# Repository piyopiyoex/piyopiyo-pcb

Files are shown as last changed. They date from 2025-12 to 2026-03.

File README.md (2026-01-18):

# Piyopiyo PCB

Piyopiyo PCB は、Elixir 入門者コミュニティ
[piyopiyo.ex](https://piyopiyoex.connpass.com/) のためのオリジナル基板です。
ワークショップや自習で扱いやすく、回路やソフトウェアも後から読み解きやすい構成を目指しています。

<p align="center">
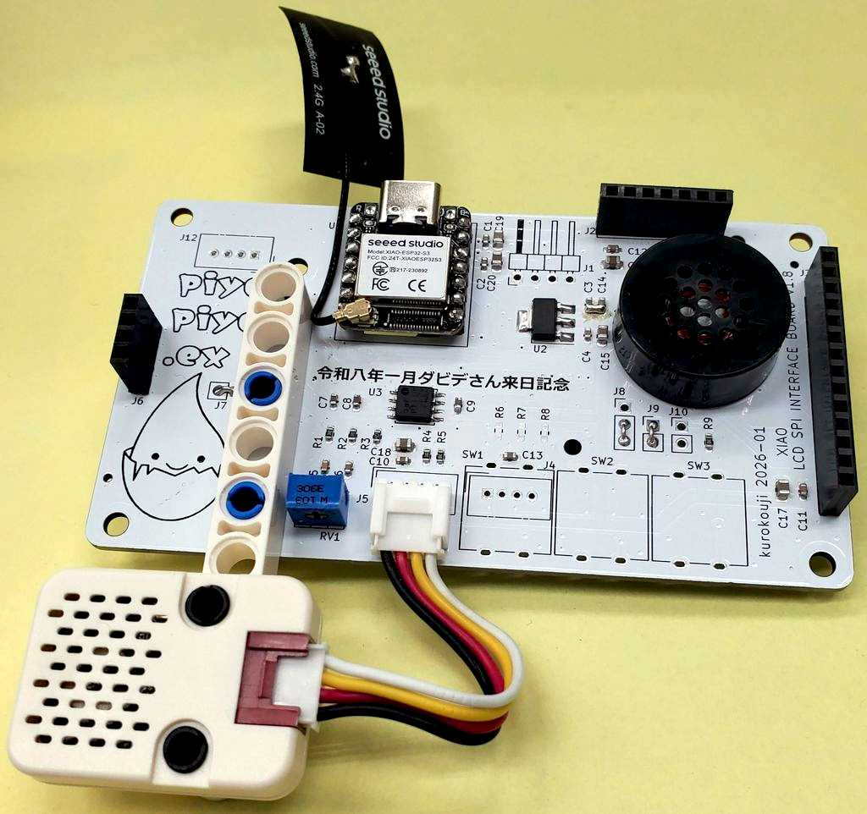
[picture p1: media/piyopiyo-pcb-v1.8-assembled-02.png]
Piyopiyo PCB assembled
  
</p>

## ハードウェア

ハードウェア設計データの概要や各ファイルの用途は、
[`hardware/README.md`](./hardware/) を参照してください。

<p align="center">
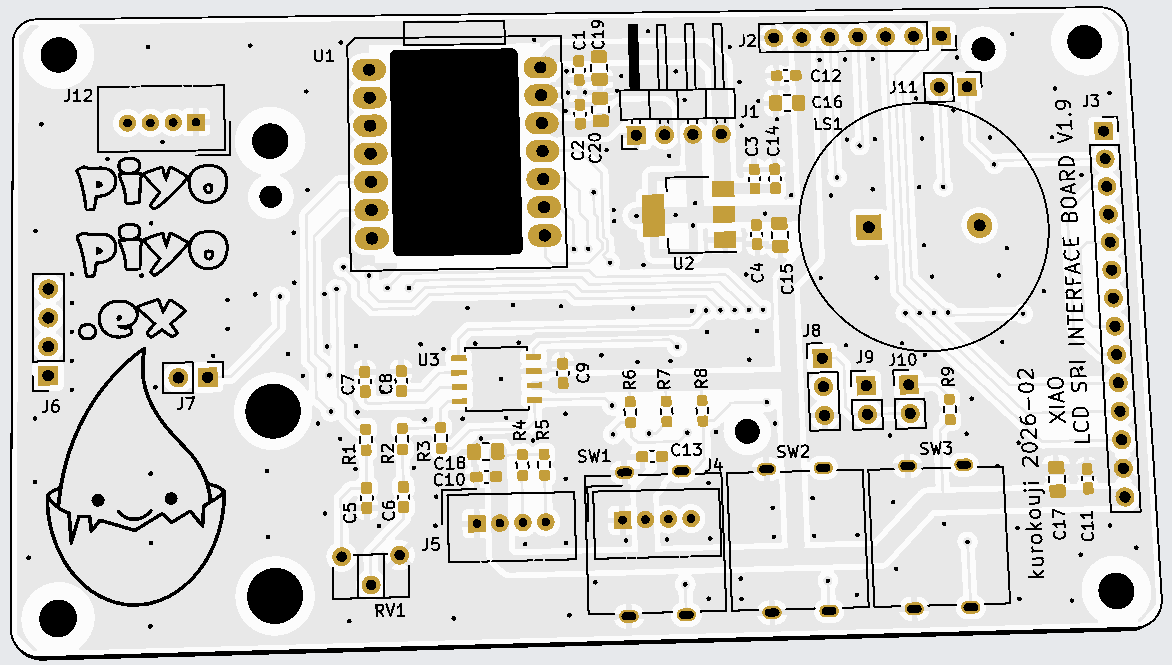
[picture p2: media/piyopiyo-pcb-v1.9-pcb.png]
Piyopiyo PCB bare board
  
</p>

## Attribution & Licensing

- ハードウェア設計（`hardware/`）: [kurokouji](https://github.com/kurokouji)
- `hardware/` は CERN-OHL-P-2.0、`manuals/` / `media/` / `.md` は原則 CC BY 4.0
- ライセンスの詳細: [`LICENSE.md`](./LICENSE.md)

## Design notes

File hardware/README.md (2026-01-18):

# hardware

`hardware/` には、Piyopiyo PCB のハードウェア設計データをまとめています。

主な内容は次のとおりです。

```text
hardware/
├── vX.Y/                         # バージョンごとの設計データ一式
│   ├── kicad/                    # KiCad プロジェクト一式（.kicad_pro/.kicad_sch/.kicad_pcb 等）
│   │   └── piyopiyo-pcb-vX.Y/    # プロジェクトフォルダ（フットプリント/ライブラリ含む）
│   ├── fab/
│   │   └── jlcpcb/               # JLCPCB 向け製造データ
│   │       ├── bom.csv           # 部品表（LCSC Part # を含む）
│   │       ├── cpl.csv           # 部品実装位置（Pick & Place）
│   │       └── gerber.zip        # 基板製造用 Gerber 一式
│   └── docs/
│       └── piyopiyo-pcb.pdf      # 回路図・基板レイアウトの PDF 出力
├── reference/                    # モジュール寸法などの参考資料
└── CHANGELOG.md                  # バージョン間の変更履歴
```

## ライセンスと帰属

このディレクトリのハードウェア設計データは kurokouji により作成されました。

ライセンスの詳細は [`LICENSE.md`](../LICENSE.md) を参照してください。

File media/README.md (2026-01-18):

# media

`media/` には、Piyopiyo PCB に関する画像ファイルをまとめています。

例:

- `piyopiyo-pcb-vX.Y-assembled.png`  
  部品を実装した基板の写真

- `piyopiyo-pcb-vX.Y-pcb.png`  
  裸基板のみの写真

どの版の写真かは、ファイル名の `vX.Y` で判別します。

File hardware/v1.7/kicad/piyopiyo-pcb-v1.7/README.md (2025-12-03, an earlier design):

# KiCad プロジェクト

このディレクトリには、Piyopiyo PCB の KiCad プロジェクトファイルをまとめています。

主なファイル:

- `.kicad_pro` — プロジェクト本体
- `.kicad_sch` — 回路図
- `.kicad_pcb` — 基板レイアウト
- `Library.pretty/` — フットプリントライブラリ
- `fp-lib-table`, `fp-info-cache` など — KiCad が生成する設定・キャッシュ

KiCad でこの版の回路やパターンを編集したい場合は、このディレクトリ内の `.kicad_pro` を開いてください。

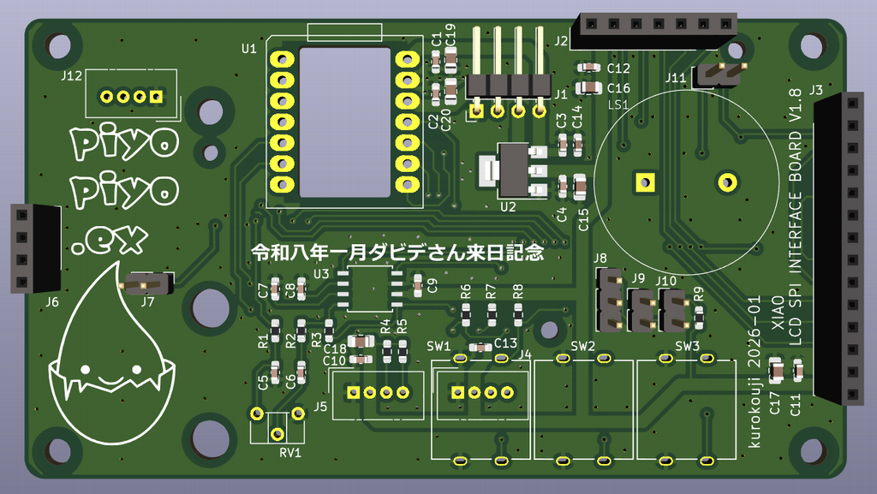
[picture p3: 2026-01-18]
media/piyopiyo-pcb-v1.8-pcb.png

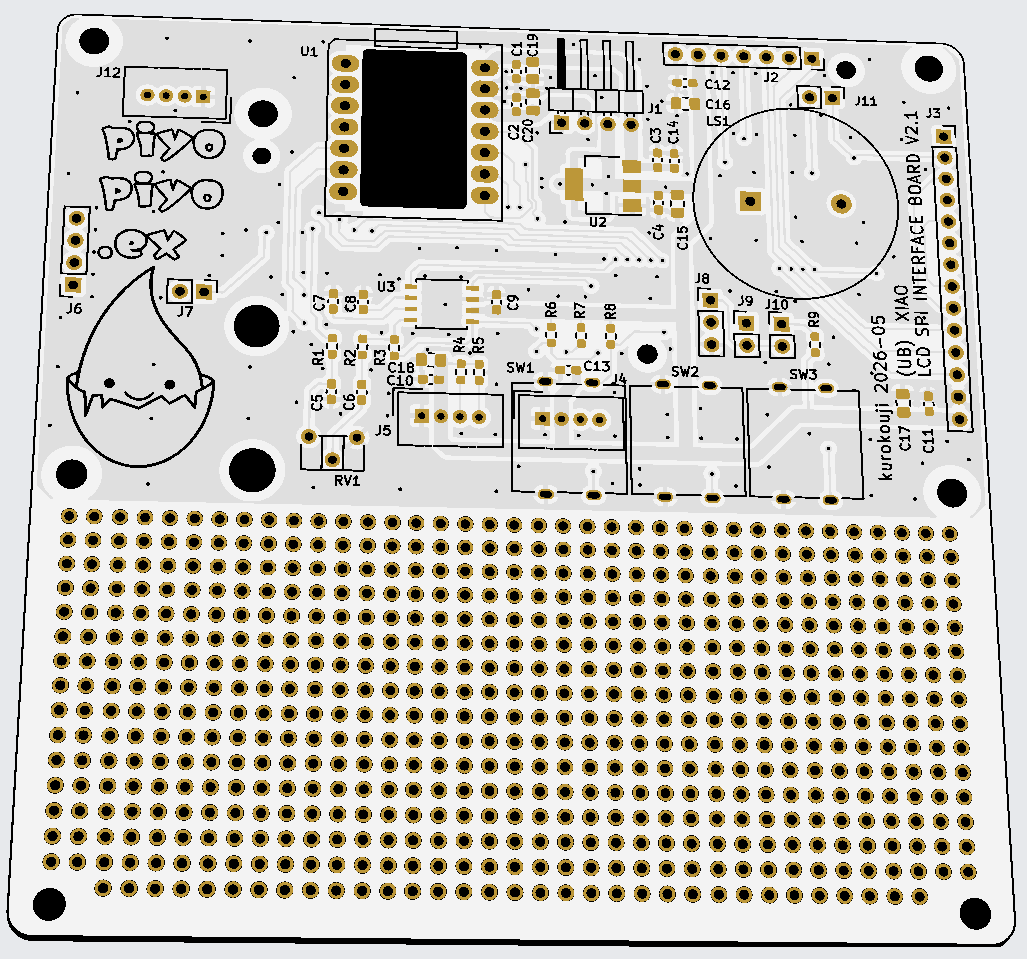
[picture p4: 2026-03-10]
media/piyopiyo-pcb-v2.1-pcb--universal-bottom.png

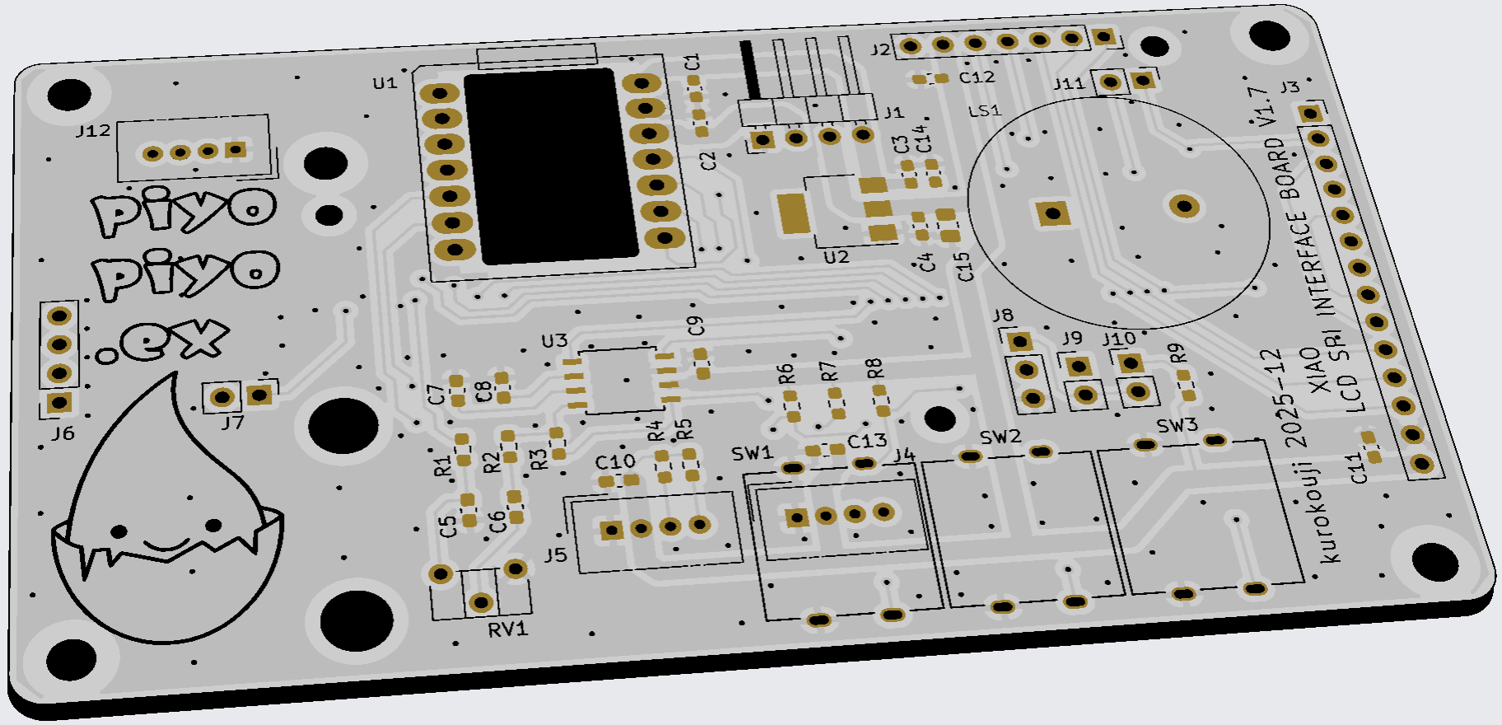
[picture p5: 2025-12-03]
media/piyopiyo-pcb-v1.7-pcb.png

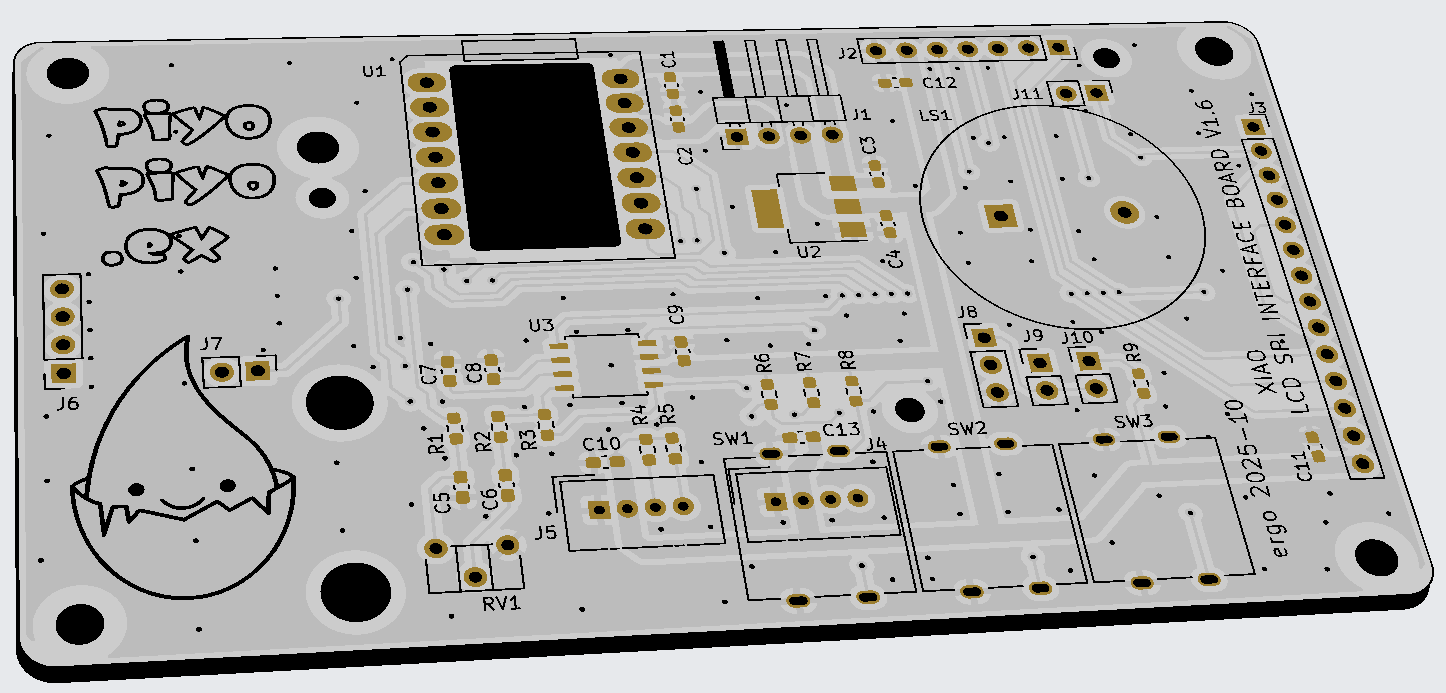
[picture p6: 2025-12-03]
media/piyopiyo-pcb-v1.6-pcb.png

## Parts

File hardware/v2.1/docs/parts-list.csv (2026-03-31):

区分 | 部品名称 | url | 参考単価 | 確認日 | 備考
基本 | piyopiyo-pcb | https://github.com/piyopiyoex/piyopiyo-pcb | 449.28 | 2026-03-09
基本 | 3.5インチspiシリアル液晶ディスプレイモジュール480*320 tftモジュールil9488 | https://ja.aliexpress.com/item/1005006201752670.html | 1589 | 2026-03-31
基本 | [118078]Seeed Studio XIAO ESP32S3 | https://akizukidenshi.com/catalog/g/g118078/ | 1480 | 2026-03-31
基本 | [109797]基板取付用スピーカーユニット 8Ω0.08W UGSM23A | https://akizukidenshi.com/catalog/g/g109797/ | 150 | 2026-03-31
基本 | [112634]Groveコネクター L型 スルーホール | https://akizukidenshi.com/catalog/g/g112634/ | 30 | 2026-03-31
基本 | 10個 NJM2113 NJM2113M JRC2113 2113 SOP8 | https://www.amazon.co.jp/dp/B0CTBSHFVH/ | 63 | 2026-03-31
基本 | [114862]半固定ボリューム TSR-3362W 10KΩ | https://akizukidenshi.com/catalog/g/g114862/ | 20 | 2026-03-31
基本 | [116155]三端子レギュレーター 3.3V AZ1117CH-3.3TRG1 | https://akizukidenshi.com/catalog/g/g116155/ | 30 | 2026-03-31
基本 | 1×7=7P ピンソケット 金メッキ 2.54mmピッチ 6個入 ＜con-013＞ | https://item.rakuten.co.jp/sapporo-boueki/con-013/ | 9.17 | 2026-03-31
基本 | 1×4=4P ピンヘッダ 金メッキ 2.54mmピッチ 6個入 ＜con-003＞ | https://item.rakuten.co.jp/sapporo-boueki/con-003/ | 7.33 | 2026-03-31
基本 | 1×4=4P ピンソケット 金メッキ 2.54mmピッチ 6個入 ＜con-004＞ | https://item.rakuten.co.jp/sapporo-boueki/con-004/ | 7.33 | 2026-03-31
基本 | 1×14=14P ピンソケット 金メッキ 2.54mmピッチ 6個入 ＜con-034＞ | https://item.rakuten.co.jp/sapporo-boueki/con-034/ | 12.83 | 2026-03-31
オプション | USR-ES1 W5500 チップ新しい SPI から LAN/イーサネットコンバータ TCP/IP Mod | https://ja.aliexpress.com/item/1005009041917816.html | 536 | 2026-03-31
オプション | ST7789 ドライブ LCD OLED ディスプレイ IPS HD TFT IC SPI 通信電圧 SPI インターフェースフルカラー DIY 240*240 3.3V Arduino 用 | https://ja.aliexpress.com/item/1005006085584965.html | 525 | 2026-03-31

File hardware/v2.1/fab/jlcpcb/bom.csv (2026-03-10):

Comment | Designator | Footprint | LCSC | Quantity
0.1u | C1,C10,C11,C12,C2,C3,C4,C6 | C_0603_1608Metric_Pad1.08x0.95mm_HandSolder | C14663 | 8
1000P | C5 | C_0603_1608Metric_Pad1.08x0.95mm_HandSolder | C1588 | 1
10K | R1,R2,R4,R5,R9 | R_0603_1608Metric_Pad0.98x0.95mm_HandSolder | C25804 | 5
10u | C13,C9 | C_0603_1608Metric_Pad1.08x0.95mm_HandSolder | C19702 | 2
1u | C7 | C_0603_1608Metric_Pad1.08x0.95mm_HandSolder | C15849 | 1
22u | C14 | C_0603_1608Metric_Pad1.08x0.95mm_HandSolder | C59461 | 1
4.7u | C8 | C_0603_1608Metric_Pad1.08x0.95mm_HandSolder | C19666 | 1
47K | R3 | R_0603_1608Metric_Pad0.98x0.95mm_HandSolder | C25819 | 1
47u | C15,C16,C17,C18,C19,C20 | C_0805_2012Metric_Pad1.18x1.45mm_HandSolder | C16780 | 6
AZ1117CH-3.3TRG1 | U2 | SOT-223 | C92102 | 1
NJM2113M-ND | U3 | NJR-DMP8_NJR | C4991123 | 1
XIAO-ESP32S3 | U1 | MOUDLE14P-SMD-2.54-21X17.8MM-S3 | C9900154951 | 1
hole_m3 | REF** | hole_m3 |  | 1
SW_D7 | SW3 | TVGP01-G73BB |  | 1
DNP | R7 | R_0603_1608Metric_Pad0.98x0.95mm_HandSolder |  | 1
LCD_DIN | J11 | PinHeader_1x02_P2.54mm_Vertical |  | 1
SW_EN(D3) | J9 | PinHeader_1x02_P2.54mm_Vertical |  | 1
DNP | R6 | R_0603_1608Metric_Pad0.98x0.95mm_HandSolder |  | 1
SW_D3 | SW1 | TVGP01-G73BB |  | 1
SD_CS | J7 | PinHeader_1x02_P2.54mm_Vertical |  | 1
PIR | J4 | NS-Tech_Grove_1x04_P2mm_Vertical |  | 1
POWER | J1 | PinHeader_1x04_P2.54mm_Horizontal |  | 1
UGSM23A | LS1 | UGSM23A |  | 1
LCD SD 4P | J6 | PinSocket_1x04_P2.54mm_Vertical |  | 1
DNP | R8 | R_0603_1608Metric_Pad0.98x0.95mm_HandSolder |  | 1
SW_D9 | SW2 | TVGP01-G73BB |  | 1
GROVE TX/RX | J12 | NS-Tech_Grove_1x04_P2mm_Vertical |  | 1
Conn_01x14_Socket | J3 | PinSocket_1x14_P2.54mm_Vertical |  | 1
BL_EN(D3) | J10 | PinHeader_1x02_P2.54mm_Vertical |  | 1
1.9 LCD 7P | J2 | PinSocket_1x07_P2.54mm_Vertical |  | 1
SP_EN(D3) | J8 | PinHeader_1x03_P2.54mm_Vertical |  | 1
10K | RV1 | Potentiometer_ACP_CA6-H2,5_Horizontal |  | 1
GROVE I2C | J5 | NS-Tech_Grove_1x04_P2mm_Vertical |  | 1

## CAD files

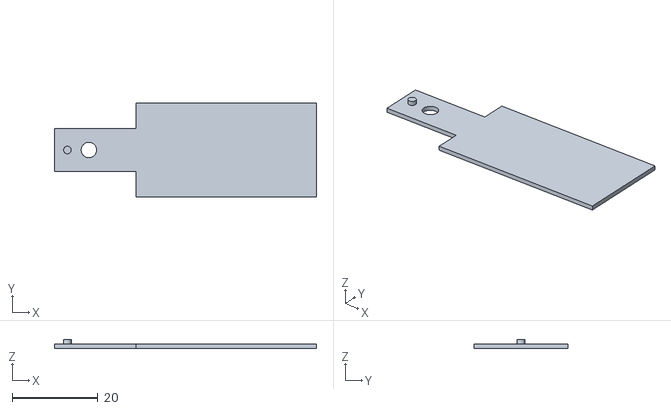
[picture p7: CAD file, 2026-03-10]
hardware/reference/xiao-antenna-support-plate.stl
61.0 x 22.0 x 2.00

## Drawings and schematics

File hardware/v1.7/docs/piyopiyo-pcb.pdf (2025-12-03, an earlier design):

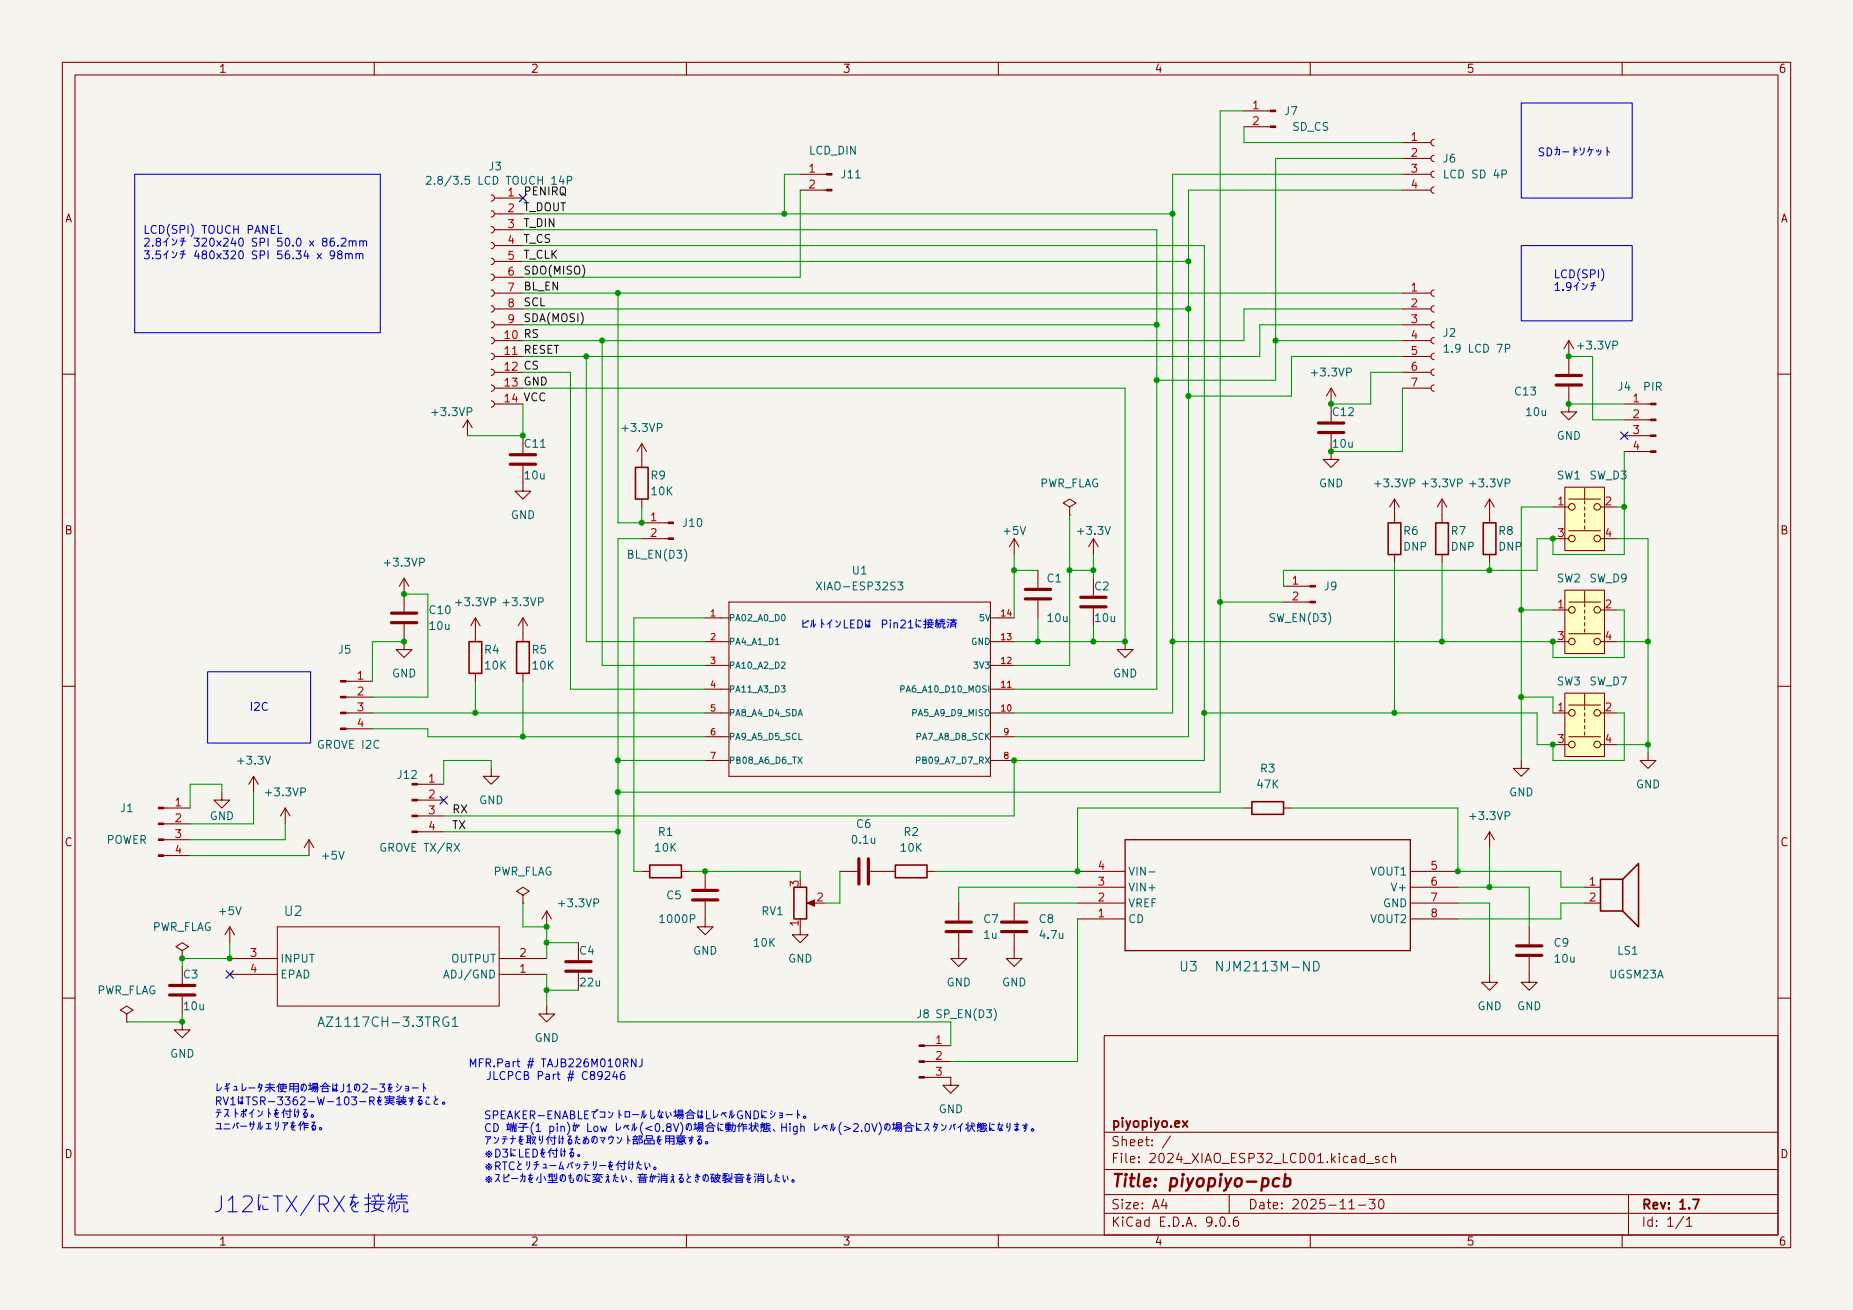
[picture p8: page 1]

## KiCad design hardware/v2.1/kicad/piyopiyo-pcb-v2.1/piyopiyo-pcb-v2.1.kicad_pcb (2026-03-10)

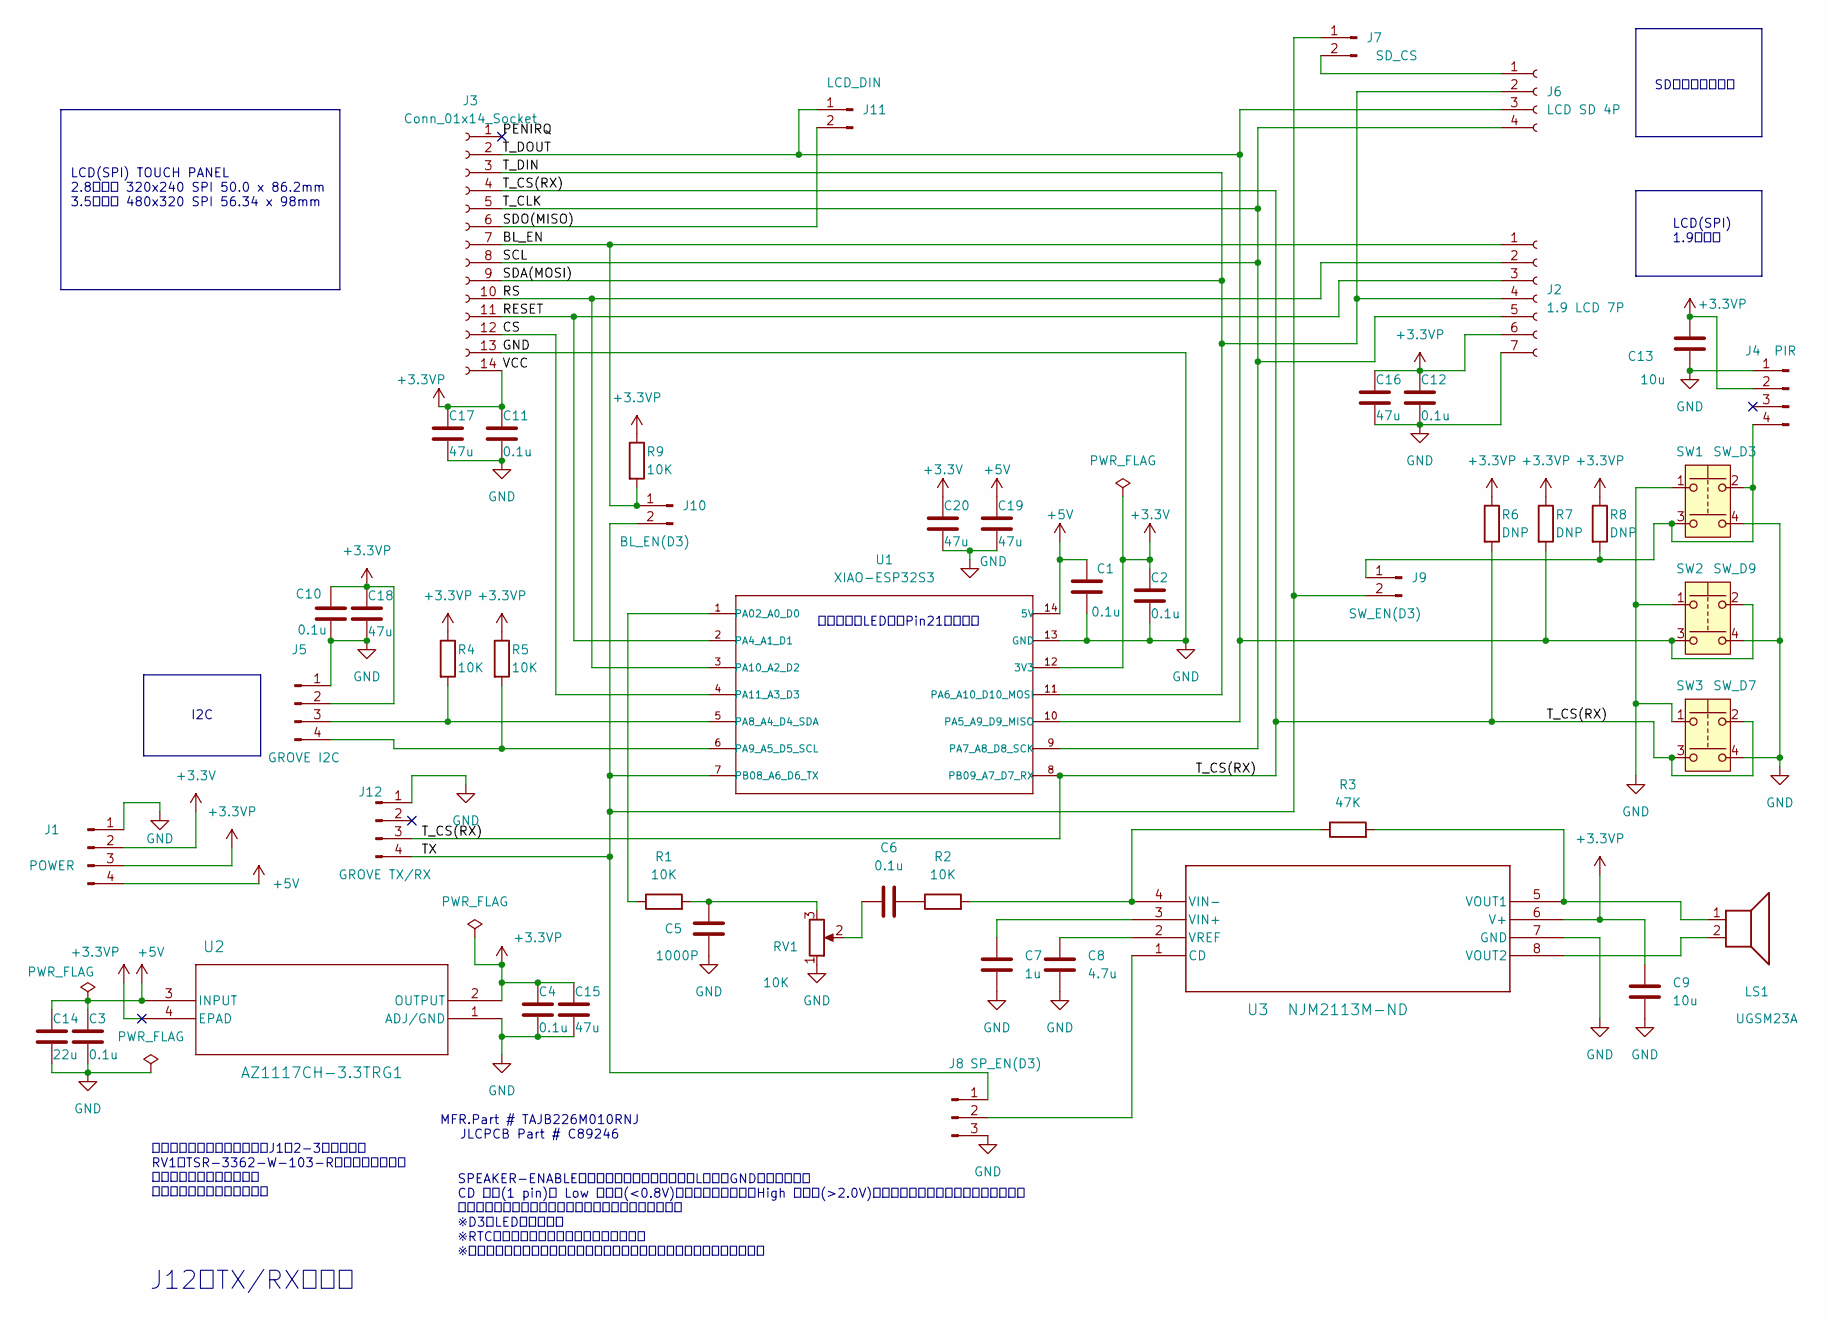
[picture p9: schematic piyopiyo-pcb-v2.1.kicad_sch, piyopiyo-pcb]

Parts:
C1, C2, C3, C4, C6, C10, C11, C12: 0.1u; C_0603_1608Metric_Pad1.08x0.95mm_HandSolder
C5: 1000P; C_0603_1608Metric_Pad1.08x0.95mm_HandSolder
C7: 1u; C_0603_1608Metric_Pad1.08x0.95mm_HandSolder
C8: 4.7u; C_0603_1608Metric_Pad1.08x0.95mm_HandSolder
C9, C13: 10u; C_0603_1608Metric_Pad1.08x0.95mm_HandSolder
C14: 22u; C_0603_1608Metric_Pad1.08x0.95mm_HandSolder
C15, C16, C17, C18, C19, C20: 47u; C_0805_2012Metric_Pad1.18x1.45mm_HandSolder
J1: POWER; PinHeader_1x04_P2.54mm_Horizontal
J2: 1.9 LCD 7P; PinSocket_1x07_P2.54mm_Vertical
J3: Conn_01x14_Socket; PinSocket_1x14_P2.54mm_Vertical
J4: PIR; NS-Tech_Grove_1x04_P2mm_Vertical
J5: GROVE I2C; NS-Tech_Grove_1x04_P2mm_Vertical
J6: LCD SD 4P; PinSocket_1x04_P2.54mm_Vertical
J7: SD_CS; PinHeader_1x02_P2.54mm_Vertical
J8: SP_EN(D3); PinHeader_1x03_P2.54mm_Vertical
J9: SW_EN(D3); PinHeader_1x02_P2.54mm_Vertical
J10: BL_EN(D3); PinHeader_1x02_P2.54mm_Vertical
J11: LCD_DIN; PinHeader_1x02_P2.54mm_Vertical
J12: GROVE TX/RX; NS-Tech_Grove_1x04_P2mm_Vertical
LS1: UGSM23A
R1, R2, R4, R5, R9: 10K; R_0603_1608Metric_Pad0.98x0.95mm_HandSolder
R3: 47K; R_0603_1608Metric_Pad0.98x0.95mm_HandSolder
R6, R7, R8: DNP; R_0603_1608Metric_Pad0.98x0.95mm_HandSolder
RV1: 10K; Potentiometer_ACP_CA6-H2,5_Horizontal
SW1: SW_D3; TVGP01-G73BB
SW2: SW_D9; TVGP01-G73BB
SW3: SW_D7; TVGP01-G73BB
U1: XIAO-ESP32S3; MOUDLE14P-SMD-2.54-21X17.8MM-S3
U2: AZ1117CH-3.3TRG1; SOT-223
U3: NJM2113M-ND; NJR-DMP8_NJR

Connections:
+3.3V: C2.1, C20.1, J1.2, U1.12 (3V3)
+3.3VP: C4.1, C9.1, C10.1, C11.1, C12.1, C13.1, C15.1, C16.1, C17.1, C18.1, J1.3, J2.6, J3.14, J4.2, J5.2, R4.1, R5.1, R6.1, R7.1, R8.1, R9.1, U2.2 (OUTPUT), U2.4 (EPAD), U3.6 (V+)
+5V: C1.1, C3.1, C14.1, C19.1, J1.4, U1.14 (5V), U2.3 (INPUT)
/BL_EN: J2.1, J3.7, J10.1, R9.2
/CS: J3.12, U1.4 (PA11_A3_D3)
/PENIRQ: J3.1
/RESET: J2.3, J3.11, U1.2 (PA4_A1_D1)
/RS: J2.2, J3.10, U1.3 (PA10_A2_D2)
/SCL: J2.5, J3.5, J3.8, J6.4, U1.9 (PA7_A8_D8_SCK)
/SDA(MOSI): J2.4, J3.3, J3.9, J6.2, U1.11 (PA6_A10_D10_MOSI)
/SDO(MISO): J3.6, J11.2
/TX: J7.1, J8.1, J9.2, J10.2, J12.4, U1.7 (PB08_A6_D6_TX)
/T_CS(RX): J3.4, J12.3, R6.2, SW3.2, SW3.3, U1.8 (PB09_A7_D7_RX)
/T_DOUT: J3.2, J6.3, J11.1, R7.2, SW2.2, SW2.3, U1.10 (PA5_A9_D9_MISO)
GND: C1.2, C2.2, C3.2, C4.2, C5.2, C7.2, C8.2, C9.2, C10.2, C11.2, C12.2, C13.2, C14.2, C15.2, C16.2, C17.2, C18.2, C19.2, C20.2, J1.1, J2.7, J3.13, J4.1, J5.1, J8.3, J12.1, RV1.1, SW1.1, SW1.4, SW2.1, SW2.4, SW3.1, SW3.4, U1.13 (GND), U2.1 (ADJ/GND), U3.7 (GND)
unnamed: C5.1, R1.2, RV1.3
unnamed: C6.1, RV1.2
unnamed: C6.2, R2.1
unnamed: J4.4, J9.1, R8.2, SW1.2, SW1.3
unnamed: J5.3, R4.2, U1.5 (PA8_A4_D4_SDA)
unnamed: J5.4, R5.2, U1.6 (PA9_A5_D5_SCL)
unnamed: J6.1, J7.2
unnamed: J8.2, U3.1 (CD)
unnamed: R1.1, U1.1 (PA02_A0_D0)
unnamed: C7.1, U3.3 (VIN+)
unnamed: R2.2, R3.1, U3.4 (VIN-)
unnamed: LS1.1, R3.2, U3.5 (VOUT1)
unnamed: LS1.2, U3.8 (VOUT2)
unnamed: C8.1, U3.2 (VREF)

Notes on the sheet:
MFR.Part # TAJB226M010RNJ JLCPCB Part # C89246
I2C
ビルトインLEDは Pin21に接続済
レギュレータ未使用の場合はJ1の2-3をショート RV1はTSR-3362-W-103-Rを実装すること。 テストポイントを付ける。 ユニバーサルエリアを作る。
LCD(SPI) 1.9インチ
SPEAKER-ENABLEでコントロールしない場合はLレベルGNDにショート。 CD 端子(1 pin)が Low レベル(<0.8V)の場合に動作状態、High レベル(>2.0V)の場合にスタンバイ状態になります。 アンテナを取り付けるためのマウント部品を用意する。 ※D3にLEDを付ける。 ※RTCとリチュームバッテリーを付けたい。 ※スピーカを小型のものに変えたい、音が消えるときの破裂音を消したい。
LCD(SPI) TOUCH PANEL 2.8インチ 320x240 SPI 50.0 x 86.2mm 3.5インチ 480x320 SPI 56.34 x 98mm
J12にTX/RXを接続
SDカードソケット

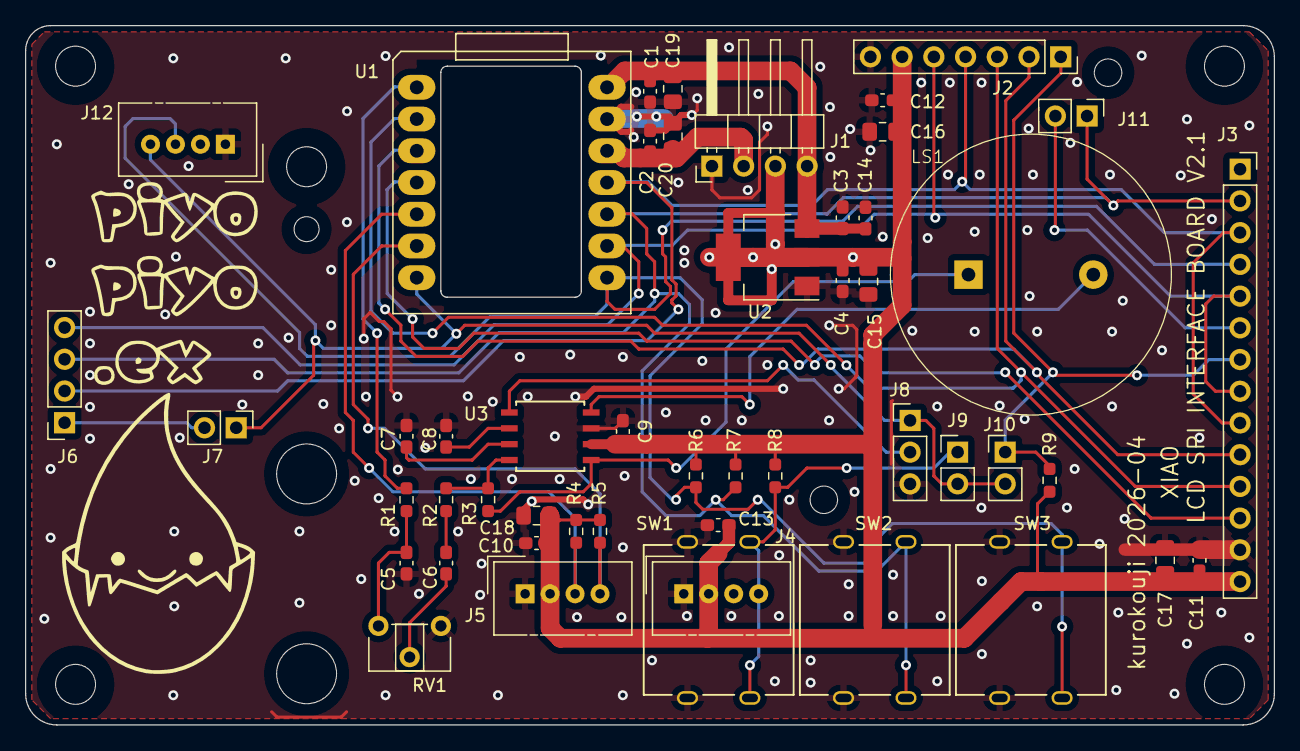
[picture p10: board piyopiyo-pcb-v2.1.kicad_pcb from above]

Board: 2 copper layers, 100.0 x 56.0 mm, 49 parts (0 on the bottom side), 28 nets.

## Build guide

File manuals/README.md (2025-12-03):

# manuals

`manuals/` には、Piyopiyo PCB に関する各種マニュアルを配置します。

- `guidebook/`
  全体の概要や、どのマニュアルをどの順番で読めばよいかの手引き

- `assembly/`
  基板の組立手順（はんだ付けの流れなど）

今後、部品手配・動作確認・ソフトウェア開発などのマニュアルも、ここに追加していく予定です。

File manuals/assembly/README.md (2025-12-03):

# 組立マニュアル

このドキュメントには、Piyopiyo PCB の組立手順（はんだ付けの流れなど）を記載していく予定です。

今後、たとえば次のような内容を追加していきます。

- 必要な工具・準備物
- 部品の確認方法
- はんだ付けのおすすめ順序
- 組立時の注意点やチェックポイント

現時点ではプレースホルダです。実際の手順が固まったら、写真や図を含めて詳しくしていきます。

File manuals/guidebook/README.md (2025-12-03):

# しおり

このドキュメントは、Piyopiyo PCB の全体像や、各マニュアルの位置づけをまとめる予定の「しおり」です。

- Piyopiyo PCB がどんな基板か
- どのマニュアルをどの順番で読むとよいか
- ワークショップや自習での使い方のイメージ

といった内容を、今後ここに整理していきます。

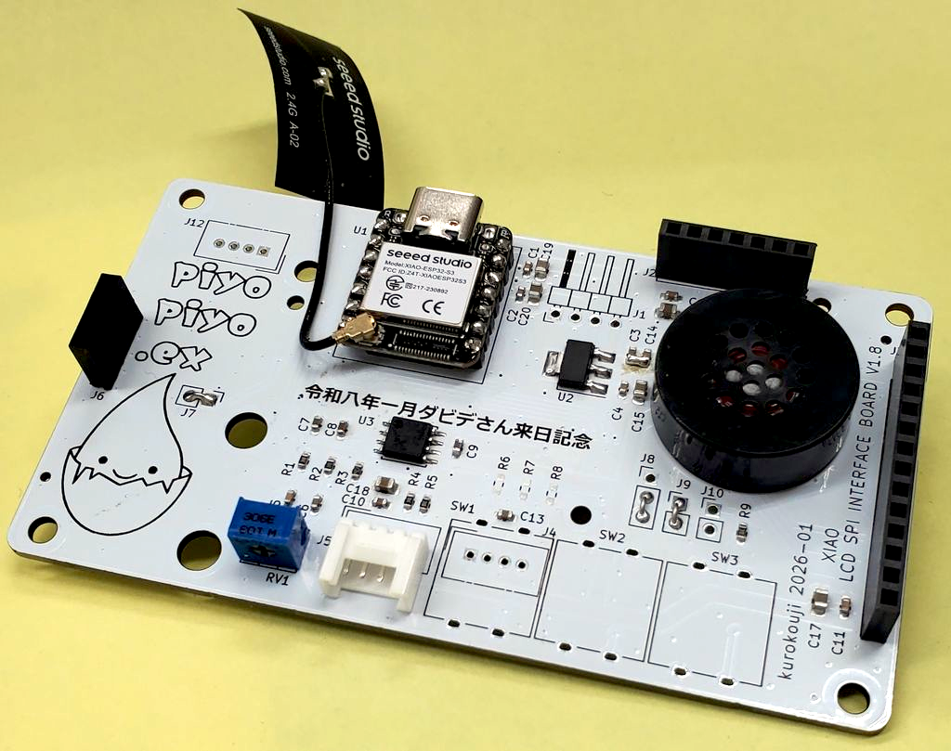
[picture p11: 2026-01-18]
media/piyopiyo-pcb-v1.8-assembled-01.png

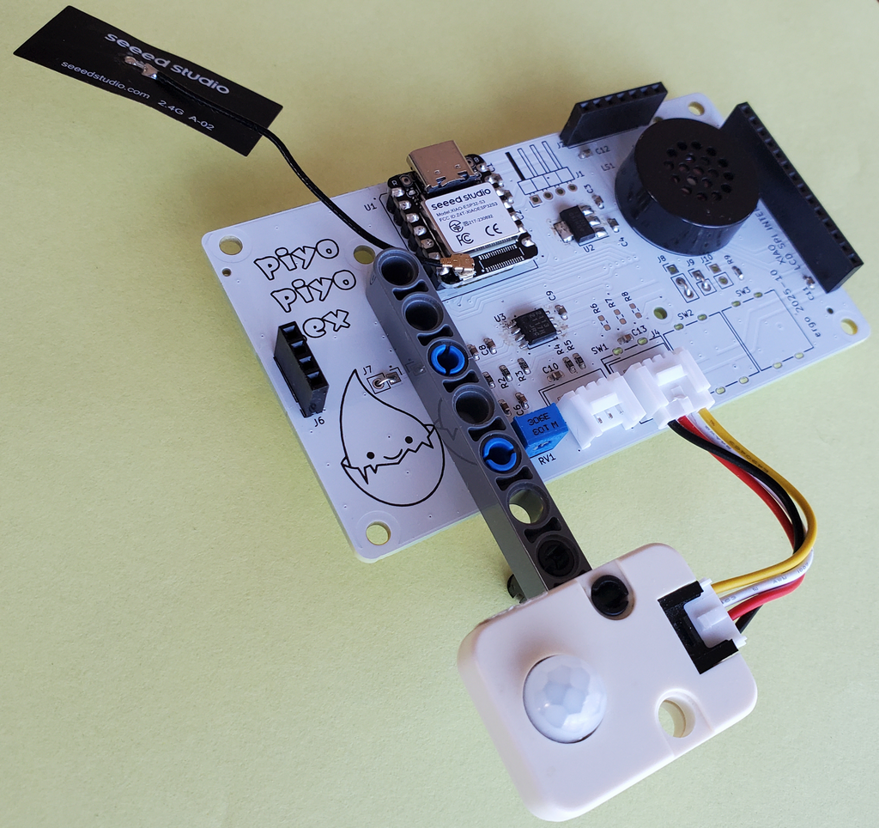
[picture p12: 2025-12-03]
media/piyopiyo-pcb-v1.6-assembled.png

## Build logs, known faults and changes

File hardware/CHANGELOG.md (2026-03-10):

# ハードウェア変更履歴

このファイルは、各バージョン間の差分を簡潔にまとめたものです。
詳細は各バージョン配下の KiCad データおよび製造データを参照してください。

## v2.1

- 回路の変更はありません
- レゴ穴の位置を変更し、M5Unitのケースが基板のエッジと干渉しないようにしました。

## v1.9

- 回路の変更はありません
- U2 の EPAD（放熱パッド）のパターンを修正し、放熱効果を向上
  - 実際にはほとんど発熱しないため、動作上の影響は小さいと見込まれます

## v1.8

- 令和八年一月 ダビデさん来日記念リリース

## v1.7

- J12 にてシリアル通信の TX/RX が利用できるように修正
- Serial1 の TX/RX コネクタに関し、ループバックテストで動作確認済み
  - T_CS と RX が重複しているため、3.5 インチ LCD 使用時は受信できません
  - 8PIN 接続の LCD では送受信の両方が利用可能です

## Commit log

2025-12-03 ハードウェア一式・画像・最小限のドキュメントを追加
    KiCad プロジェクト、BOM/CPL、PDF、参考資料などを `hardware/` 以下に追加。
    基板写真を `media/` に配置し、各ディレクトリに最小限の README を整備。
    トップレベルの README と .gitignore も更新。
    [piyopiyo-pcb-v1.7.kicad_pcb, piyopiyo-pcb-v1.7.kicad_sch, piyopiyo-pcb.v1.7.bom.xlsx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]
2026-01-17 README.md の文言変更
2026-01-18 v1.9 ドキュメント追加とフォルダ構成整理
    [bom.csv, piyopiyo-pcb-v1.7.kicad_pcb, piyopiyo-pcb-v1.7.kicad_sch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]
2026-03-10 XIAOアンテナ用の羽子板3Dデータ追加
    [xiao-antenna-support-plate.stl]
2026-03-10 v2.1 ドキュメント追加
    [bom.csv, piyopiyo-pcb-v2.1.kicad_pcb, piyopiyo-pcb-v2.1.kicad_sch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]
2026-03-31 docs(hardware): add v2.1 community parts list
    [parts-list.csv]
